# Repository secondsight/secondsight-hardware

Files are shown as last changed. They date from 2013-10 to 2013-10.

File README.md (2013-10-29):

secondsight
===========

3D Printable Head Mount Display for secondsight &amp; associated peripherals licensed under [Mozilla Public License, v. 2.0.](https://github.com/secondsight/secondsight-hardware/blob/master/LICENSE)

## Contents

- Example Assemblies
- Preparing to Build a Headset
- Building the Headset
- 3D Printing Plates & STL File Descriptions
- Source Files & Customisation
- Non-Source Files
- Logo

## Example Assemblies

Some of the STLs are not meant to be printed. They are just documentation to
show how that variant fits together. The names are the same as the variant file
with *-assembled* inserted before the extension - these are meant for assembly reference and 3D viewing.

You can view the final product here;

[Visor-C Assembled](https://github.com/secondsight/secondsight-hardware/blob/master/visor-C-assembled.stl) and [Visor-D Assembled](https://github.com/secondsight/secondsight-hardware/blob/master/visor-D-assembled.stl)

## Preparing to Build a Headset

There a few pre-requisites that you need to build the secondsight headset from
this project.

   1. Lenses
   2. Head strap
   3. 3D printer
   4. Android phone
   5. Open cell foam or neoprene

### Lenses

We have had reasonable luck with lenses in the 25mm to 37mm diameter range,
with a focal length of 50mm. The field of view is directly related to the
diameter of the lens. A 35-37mm diameter lens seems to give a view that covers
the whole phone at this focal length. A 25mm lens doesn't quite cover the whole
phone.

We have tried as high as 50mm diameter. That lens had a field of view larger
than the phone and required a larger visor design.

The current design is currently set for the 36mm Lens from [B&L 5X Aspheric Pocket Magnifier](http://www.amazon.com/Bausch-Lomb-Aspeheric-Packette-5x/dp/B000M755GK). We will be releasing our own pcx lens designs soon.

### Head strap

While you could use the headset by holding it to your face with your hands,
this would get old really quick. The headset is designed to use a 40mm wide
elastic strap to hold the headset. This gives good support without requiring an
extremely tight fit to avoid slipping.

### 3D Printer

You should be able to use any 3D printer with a large enough build volume. The
visor has been successfully printed in both ABS and PLA.

### Android Phone

The current visor design is optimized for the Galaxy S4 phone. The design does
not require exactly that phone, but it the front of the visor was designed around
the dimensions of the S4. It has been used with different phones that are close
to the same dimensions (e.g. Galaxy Nexus).

### Open Cell Foam or Neoprene

The hard plastic is mildly uncomfortable fitting directly against your face.
It's not painful, but it is hard plastic supporting a phone. A small amount of
foam applied to the back side of the visor makes the fit much more comfortable.

A cheap source of reasonable material is a cheap mousepad. You can easily cut
pieces to fit the visor.

## 3D Printing Plates & STL File Descriptions

To get a full visor, you will need to print one of the body variants
(*visor-C.stl* or *visor-D.stl*), the *lens_holders.stl* and the
*optics_support.stl*.

### visor-C.stl

In this variant, the body slopes smoothly from the face to the phone with no
flaring at all. The optics mounting hardware is printed inside the visor.

### visor-D.stl

In this variant, the body slopes smoothly from the face to the phone with no
flaring at all. The corners are slightly grooved to give less of a round feel.
The optics mounting hardware is printed inside the visor.

### lens\_holders.stl

This file contains the parts that support the lenses themeslves. The lens is
held between the longer barrel and the cap. This file contains parts for a pair
of lens holders.

### optics\_support.stl

This file contains the two support plates that connect the lens holders to the
visor body.

## Source Files & Customisation

Most of the source code for the hardware consists of OpenSCAD files.

### visor.scad

This is the main file that collects and assembles the parts the make up the
visor.  It has a number of parameters that control the final visor look.

#### Variants

Currently, we have two variants of the main structure of the visor: **C**
and **D**. Earlier prototypes were listed as variants A and B, but they are
no longer supported. In addition, you may want to print either the whole
visor or just parts of it. There are a pair of variables that allow you to
choose what variations you want to print.

   * variant - Choose the variant to print by setting this variable to the
     appropriate string
      - "C": See *visor-C.stl* above for a description. Used by the Makefile to
        generate *visor-C.stl*.
      - "D": See *visor-D.stl* above for a description. Used by the Makefile to
        generate *visor-D.stl*.
   * plate - Choose the subset of the visor to print.
      - "body": Print the main body of the visor.
      - "optics\_support": Print the lens support plates.
      - "lens\_holders": Print the lens holders.
      - "full\_optics": Print the lens holders and support plates all at once.
        Requires a fairly large build area. Not recommended.
      - "assembled": Show the assembled visor. Not printable!

You can either change these parameters in the *visor.scad* file or supply them
on the OpenSCAD command line if you want to automatically generate the STLs.
See the Makefile for examples of the use of these parameters.

#### Experimenting with Assembled View

There are a few parameters that you can change in the *assembled* view to get
an idea of how the visor will work in reality. Supplying a different value for
*lens* gives an idea of how the visor would look with that lens. Obviously,
this is easy for one of the defined lenses, and harder if you just want to try
out a lens. See the file *lenses.scad* to define a new lens to try.

Inside the optics\_assembled module, there are two potentially tweakable
parameters. The *xoff* value is half the IPD (Inter-Pupilary Distance). You can
either supply this directly or use one of the constants defined at the top of
*visor.scad*.

   * IPD\_min - minimum value for adults
   * IPD\_max - maximum value for adults
   * IPD\_avg - average value for adults
   * IPD\_avg\_male - average value for adult males
   * IPD\_avg\_female - average value for adult females

The other tweakable parameter is *lens_z*, which specifies the distance between
the phone and the lens. Normally, we use the defined value for the lens, but
you can change this value to see how the visor would look with the lens closer
to the phone or farther away.

#### User-Specific Parameters

The visor is currently configured to fit most adults relatively well. However,
there is a possibility that the visor could be more comfortable for a given
user by changing the fit slightly. The file *user_params.scad* contains a set
of user-specific changes for this purpose.

See the documentation below for a description of these parameters.

#### Phone-Specific Parameters

The visor is designed to work with the Galaxy S4. There should be little
difference from phone to phone. These parameters will only be changed to target
a different phone as the primary design.

These parameters should not be changed in most cases.

### visor\_body.scad

This file defines the main shape of the body of the visor. This is purely a
library file and generates no object if loaded directly. The *visor.scad* file
loads this *visor_body.scad* and calls the *main_body()* module to instantiate
the body.

### visor\_elastic\_mount.scad

This file defines the elastic band mounting system for the phone. Although not
the *coolest* design, this is functional and allows testing of the hardware.
It's main advantage is that it is simple and works with all phones.

### visor\_optics\_mount.scad

This file defines the hardware to support the lenses in the visor body. The
design has a few constraints that make the problem of mounting interesting.  We
want the lens to be held firmly, but weight is a consideration. Also not all
users are the same. Also, the *Interpupillary Distance* (IPD) is different from
person to person. We would like this to be easily adjustable for the user.

The optics mounting hardware takes these issues into account.

### optic\_plate\_support.scad

Defines the pieces of the model that supports the optics lens front plate in
the body of the visor. Defines the ledges, the tabs and the slots.

### lenses.scad

This file contains functions to define and use descriptions of particular
lenses. We want designs to be able to depend on both the physical and optical
characteristics of a lens, without having a bunch of random constants to deal
with (and pass around). This file defines a vector structure and accessors to
keep those parameters in check.

#### lens\_descriptor(name)

This function returns the vector that describes a lens we already know. You
can think of it as a factory object for known lenses. It currently has values
for the lenses we used in prototyping.

#### Accessor methods

Each accessor takes the lens description as a parameter and returns the
requested data from the vector. This is a lot more readable than just dealing
with random vector indices. All lengths are in mm.

   * lens\_diam(lens) - lens diameter
   * lens\_focal\_length(lens) - focal length
   * lens\_phone\_offset(lens) - measured nominal distance from lens to phone
   * lens\_fov(lens) - measured minimum field of view at the phone\_offset
   * lens\_rim\_thickness(lens) - thickness of the rim of the lens
   * lens\_front\_height(lens) - distance from rim to the front of the lens
   * lens\_thickness(lens) - overall thickness of the lens
   * lens\_back\_height(lens) - distance from the rim to the back of the lens

### polybody.scad

The visor body is designed around a ten-sided polyhedron. Some of the
parameters and code for this polyhedron are needed in multiple files.
Separating the code into this file makes it easier to reuse.

### user\_params.scad

This file contains only constants that describe some user-specific sizes.

Although we don't expect these to change, a particular user might be able to
get a better fit by changing the user-specific parameters.

   * *user_temple_distance* - distance from temple to temple in mm.
   * *forehead_depth* - distance from temple to front of forehead in mm.
   * *eye_forehead_offset* - inset distance of eyes from forehead

We will try to get these parameters reasonable for most adults, but tweaking
them may generate a more comfortable fit.

The only one that is likely to change much would be *user_temple_distance*.
People with wider or narrower faces may want to change this parameter.

## Non-Source Files

### Makefile

To simplify the creation of STL files from the OpenSCAD source, the project
also includes a *Makefile*. You can use most variants of the *make* development
tool to generate the STLs from the command line. The Makefile contains two
variables that probably require changing to use in your environment.

   * *OPENSCAD* - full path to the OpenSCAD program on your system
   * *SLIC3R* - (optional) full path to the slic3r program on your system

You do not need to use slic3r to generate your gcode files. If you do, the
Makefile contains targets to help.

### config.ini

This is a *slic3r* configuration that has been used to create gcode files for
the visor STLs.

## Logo

The font used in the logo uses the OpenSans Regular font, which has been ported
for use with OpenSCAD by the Brad Pitcher. His implementation is available at
http://www.thingiverse.com/thing:13677 and is released under a CC by-sa
license.

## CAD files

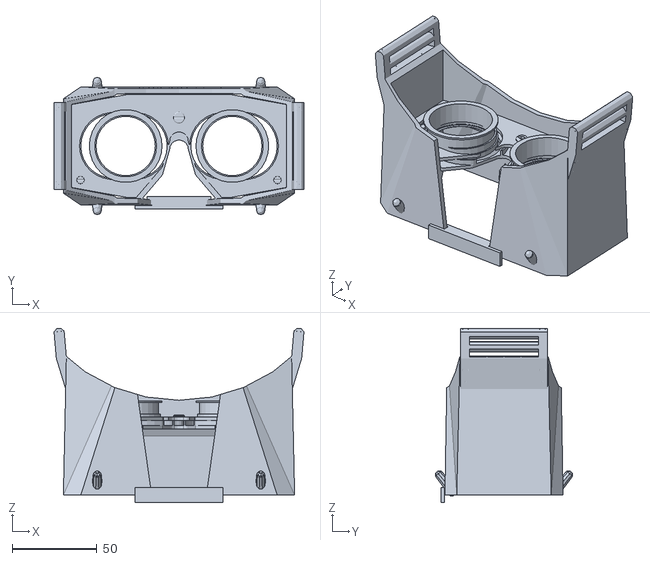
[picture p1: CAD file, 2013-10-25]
visor-D-assembled.stl
147.7 x 81.1 x 103.0

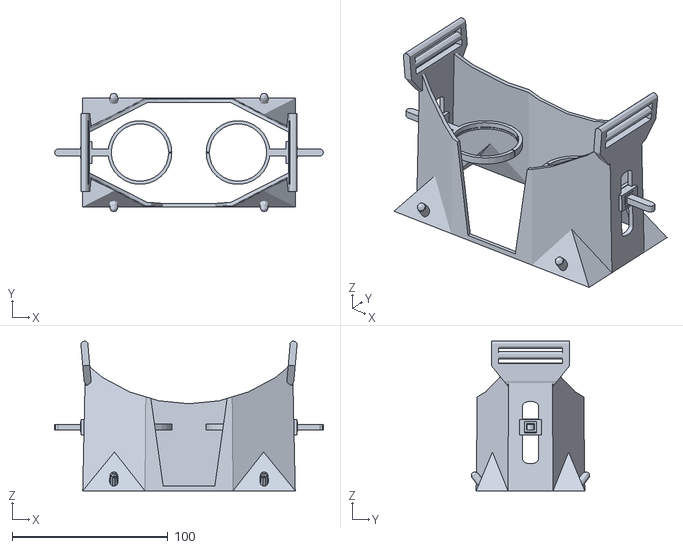
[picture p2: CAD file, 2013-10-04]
visor-assembled.stl
172.8 x 76.1 x 96.3

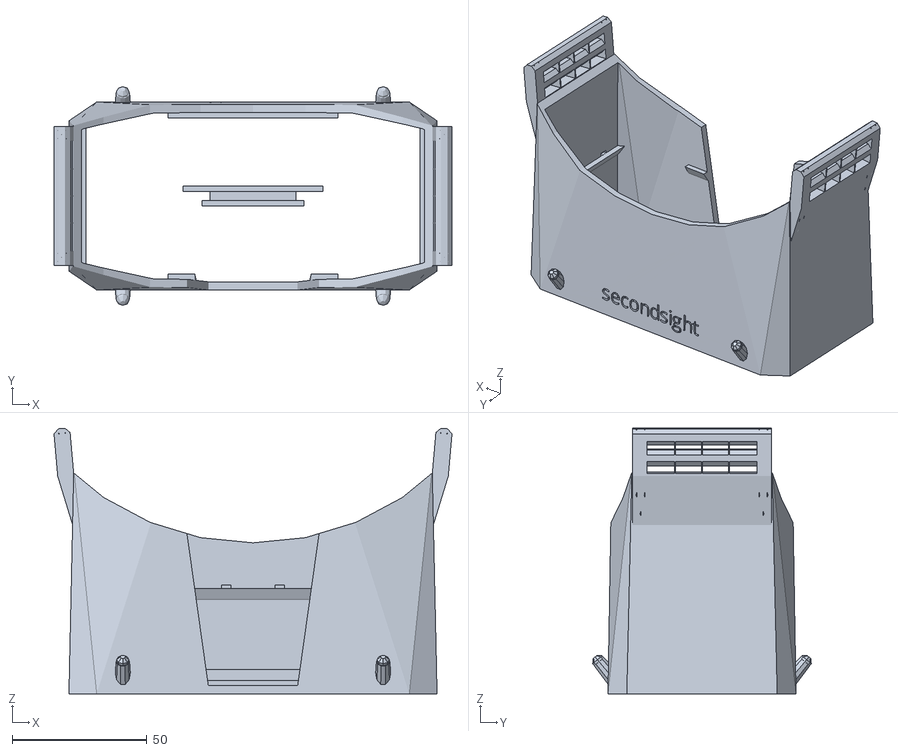
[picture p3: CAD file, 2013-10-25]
visor-C.stl
147.7 x 81.1 x 98.5

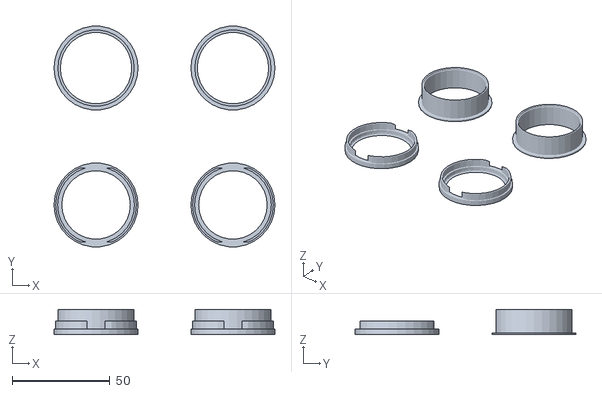
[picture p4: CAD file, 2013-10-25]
lens_holders.stl
113.0 x 112.8 x 13.0

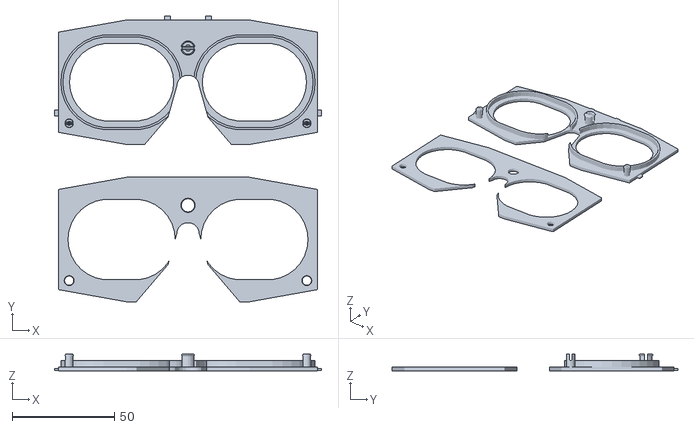
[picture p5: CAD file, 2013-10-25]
optics_support.stl
130.7 x 139.8 x 8.25

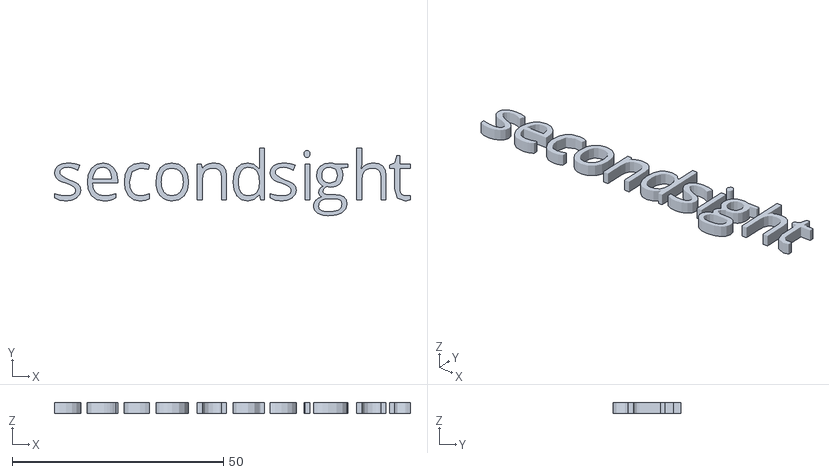
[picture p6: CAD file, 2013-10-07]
secondsight_logo.stl
84.2 x 16.0 x 2.50

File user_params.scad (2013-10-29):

/* This Source Code Form is subject to the terms of the Mozilla Public
 * License, v. 2.0. If a copy of the MPL was not distributed with this
 * file, You can obtain one at http://mozilla.org/MPL/2.0/. */

// secondsight Visor project
// Copyright 2013 by secondsight.io, Some Rights Reserved.
//
// Definition of user-specific parameters for the secondsight hardware

user_temple_distance=116; // temple-to-temple distance
forehead_depth=27.5;      // temple to front of forehead distance
eye_forehead_offset=5;    // distance from forehead to eye

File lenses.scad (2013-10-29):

/* This Source Code Form is subject to the terms of the Mozilla Public
 * License, v. 2.0. If a copy of the MPL was not distributed with this
 * file, You can obtain one at http://mozilla.org/MPL/2.0/. */

// secondsight Visor project
// Copyright 2013 by secondsight.io, Some Rights Reserved.
//
// Standardize a lens description for the secondsight headset.

//  Creating a pseudo-object using a vector and a set of functions to access
//  the defined attributes.

function lens_descriptor(name) = (name == "ebay 50x50") ? [ 50, 50, 42, 75, 2, 7.35, 12.45 ]
    : name == "edmund 25x50" ? [ 25, 50, 44, 50, 1.25, 3, 4.25 ]
    : name == "edmund 25x25" ? [ 25, 25, 23, 30, 1.25, 6.15, 7.4 ]
    : name == "b&l 35 5x"    ? [ 37, 50, 41, 60, 1.9, 3, 8 ]
    : [];

function lens_diam( lens ) = lens[0];
function lens_rad( lens ) = lens[0]/2;
function lens_focal_length( lens ) = lens[1];
function lens_phone_offset( lens ) = lens[2];
function lens_fov( lens ) = lens[3];
function lens_rim_thickness( lens ) = lens[4];
function lens_front_height( lens ) = lens[5];
function lens_thickness( lens ) = lens[6];
function lens_back_height( lens ) = lens[6]-lens[5]-lens[4];

// Define a model of the lens described by 'lens'
//
// lens - descriptor for the lens to model
module lens_model( lens )
{
    union()
    {
        //front
        if( lens_front_height(lens) > 0 )
        {
            assign( rad_up=(lens_rad(lens)*lens_rad(lens)+lens_front_height(lens)*lens_front_height(lens))/(2*lens_front_height(lens)) )
            {
                translate( [0,0,lens_rim_thickness(lens)/2] )
                intersection()
                {
                    translate( [0,0,lens_front_height(lens)-rad_up] )
                        sphere( r=rad_up, center=true, $fn=50 );
                    cylinder( r=lens_rad(lens), h=lens_front_height(lens) );
                }
            }
        }
        //rim
        cylinder( h=lens_rim_thickness(lens), r=lens_rad(lens), center=true );
        //back
        if( lens_back_height(lens) > 0 )
        {
            assign( rad_up=(lens_rad(lens)*lens_rad(lens)+lens_back_height(lens)*lens_back_height(lens))/(2*lens_back_height(lens)) )
            {
                translate( [0,0,-lens_rim_thickness(lens)/2] )
                intersection()
                {
                    translate( [0,0,-lens_back_height(lens)+rad_up] )
                        sphere( r=rad_up, center=true, $fn=50 );
                    translate( [ 0,0, -lens_back_height(lens) ] ) cylinder( r=lens_rad(lens), h=lens_back_height(lens) );
                }
            }
        }
    }
}

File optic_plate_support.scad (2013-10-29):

/* This Source Code Form is subject to the terms of the Mozilla Public
 * License, v. 2.0. If a copy of the MPL was not distributed with this
 * file, You can obtain one at http://mozilla.org/MPL/2.0/. */

// secondsight Visor project
// Copyright 2013 by secondsight.io, Some Rights Reserved.
//
//  Define the tab/slot system for attaching the optics plate to the body.

// Fit factors
slide_gap=0.25;
fit_gap=0.15;

// Tab sizing
tab_length=3;
tab_height=1;

module support_slot( depth )
{
    long=tab_length+2*slide_gap;
    height=tab_height+2*fit_gap;
    translate( [ 0, 0, height/2 ] ) cube( [ long, depth, height ], center=true );
}


module support_tab( depth )
{
    long=tab_length;
    height=tab_height;
    translate( [ 0, 0, height/2 ] ) cube( [ long, depth, height ], center=true );
}

module support_ledge_slots( x_off, y_off, z_off )
{
    gap=1.1;
    depth=2;
    spread=10;
    drop=15+gap;
    translate( [-spread, y_off+gap, z_off+0.1] ) support_slot( depth );
    translate( [ spread, y_off+gap, z_off+0.1] ) support_slot( depth );
    translate( [ x_off+gap, -drop, z_off+0.1] ) rotate( [ 0, 0, 90 ] ) support_slot( depth );
    translate( [-(x_off+gap), -drop, z_off+0.1] ) rotate( [ 0, 0, 90 ] ) support_slot( depth );
}

module support_ledge_tabs( x_off, y_off, z_off )
{
    gap=1.1;
    fudge=0.1;
    depth=gap+1-fit_gap;
    spread=10;
    drop=15;
    gap_off=depth/2-fudge;
    translate( [-spread, y_off+gap_off, z_off+fudge] ) support_tab( depth );
    translate( [ spread, y_off+gap_off, z_off+fudge] ) support_tab( depth );
    translate( [ x_off+gap_off, -drop, z_off+fudge] )  rotate( [ 0, 0, 90 ] ) support_tab( depth );
    translate( [-(x_off+gap_off), -drop, z_off+fudge] ) rotate( [ 0, 0, 90 ] ) support_tab( depth );
}

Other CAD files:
visor-C-assembled.stl
visor-D.stl
hmd.scad
polybody.scad
viewer_body.scad
visor.scad
visor_body.scad
visor_elastic_mount.scad
visor_optics_mount.scad

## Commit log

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2013-09-12 First attempt at front mount.
    Still pretty blocky and I need to check the angle for printing.
    [viewer_body.scad]
2013-09-13 Corrected widths error.
    I had forgotten about converting the 'face-to-face' width to a radius
    before generating the cylinders. This change the code to take that into
    account.
    I also sloped the main body. Despite the mistake, the side of the viewer
    that fit against the face was almost perfect, even if it wasn't what I
    planned. Now, the front is better suited to match the phone and the back
    should still fit against the face.
    [viewer_body.scad]
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2013-09-13 Final cleanup of this pass.
    Push unimportant details down as far as possible. The two polyprism
    modules now deal with all of the fiddly bits instead of spreading the
    details over multiple modules.
    Remove some unnecessary variables.
    Add some comments for later readability.
    [viewer_body.scad]
2013-09-13 Adjust angle to reduce chance of overhang failure.
    [viewer_body.scad]
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2013-09-13 Close bottom front for stability.
    [viewer_body.scad]
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2013-09-13 Modify the strap holders for comfort.
    The straight up version of the strap holder fit a little tight against
    the temples. This version has them lean outward about 5 degrees on each
    side. Hopefully this is more comfortable.
    [viewer_body.scad]
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2013-09-16 Restructure the scad files.
    Separating major components of the code into separate scad files to
    simplify making different variants without a whole lot of conditionals.
    The main body deserves it's own component.
    The phone mount will change, so it has it's own component.
    Added a main file that brings together components.
    Also renamed "viewer" to "visor". Better term.
    [visor.scad, visor_body.scad, visor_elastic_mount.scad]
2013-09-16 Modify test variant for mount test.
    Modified the "test" variant so that I'm only printing the front part
    of the visor. This exposes the elastic mount points for testing without
    requiring the whole visor.
    [visor.scad]
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2013-09-16 Improve elastic mount printability.
    The mount points failed in terms of the look of the print. Structurally,
    they did pretty well.
    Hopefully these changes and the cooling changes in config.ini will
    result in a better print.
    [visor_body.scad, visor_elastic_mount.scad]
2013-09-16 Reduce dependence on globals.
    Modified several modules to take parameters instead of depending on the
    global values. Added more documentation for the new parameters.
    [visor.scad, visor_body.scad]
2013-09-16 Make the wall thickness consistent in x and y.
    The code I was using to "squash" the rectangle and octagon had a flaw
    that reduced the size of the walls at the top and bottom of the visor.
    Once I realized what it was, the fix was pretty obvious.
    [visor_body.scad]
2013-09-17 New design for strap mount.
    Make the strap mount a little thinner.
    Make two slots to lock the strap in place
    Lengthen the mount slightly.
    [visor.scad, visor_body.scad]
2013-09-17 Replace the square center rod with an octagon.
    This looks like a much nicer fit. I need to print to see if it is strong
    enough.
    [visor_body.scad]
2013-09-18 First attempt failed because top wasn't strong enough.
    [visor_body.scad]
2013-09-18 Make slots for optics mounts.
    Also corrected the forehead_depth parameter, which I had mis-labeled.
    Extended depth to match optics information from Dmitry.
    [visor.scad, visor_body.scad, visor_optics_mount.scad]
2013-09-18 Fix strap mount height.
    [visor_body.scad]
2013-09-18 Add STLs to git.
    Jarrad pointed out that github has an STL diff viewer now.
    Add the main STLs to version control.
    Fix .gitignore to not ignore STLs.
    Modify the Makefile to make generating main STLs easier.
    [visor-A.stl, visor-B.stl]
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2013-09-18 Correct merging error.
    [visor.scad, visor_body.scad]
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2013-09-18 First try at a lens holder.
    Based on the dive design. Not any clips, yet. It will be hard to design
    that part until I get the lenses in the mail.
    [visor_optics_mount.scad]
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2013-09-19 Attempt a better fit for slider.
    Tighten the inside/outside fit, so that gluing is not required.
    Tighten the slot fit so that it doesn't wiggle as much.
    Add slope to the hole for the lens holder to make it parallel to the
    phone.
    [visor.scad, visor_optics_mount.scad]
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2013-09-19 Prepare main file to print whole visor.
    Set up both A and B variants to print with the optics mounting hardware
    on the same plate as the visor body.
    [visor.scad]
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2013-09-19 Make it possible to print in parts.
    Added a part parameter that allows for printing the body, the optics
    support, or both.
    [visor.scad]
2013-09-19 Adjust the slider a little more.
    Spacing between inside and outside corrected.
    Add a little spacing to allow lens holder to move.
    [visor_optics_mount.scad]
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2013-09-20 Better fit for slider outside.
    Modified the slider so that the core should go all of the way through.
    Marked the top of the piece slightly to make assembly easier.
    [visor_optics_mount.scad]
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2013-09-20 Correct outside slider through-hole.
    The new version resulted in an outside slider with a solid piece through
    the hole. Extend the cut to make certain it stays.
    [visor_optics_mount.scad]
2013-09-20 Add support for generating an "assembled" STL.
    This STL serves as documentation for how the parts should fit together.
    [visor-assembled.stl, visor.scad]
2013-09-20 Move the 'top of slider' marks.
    For some reason, the little cylinder on the outside slider caused a
    glitch in slic3r that created a filled layer all the way across when
    the little cylinder marker was on the lip. Moved to top without
    side-effects. Made the same change to the inside slider, because it was
    invisible on the original.
    [visor_optics_mount.scad]
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2013-09-23 Refactor to make changing lens parameters easier.
    Factored out the lens diameter.
    Calculate some values relative to the lens parameters.
    Added transparent lenses to the assembled view to help visualize
    the offsets better.
    [visor.scad, visor_optics_mount.scad]
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2013-09-26 Add support for a lens description.
    Lenses are a little too complicated to be described with a couple of
    numbers to pass around. The file lenses.scad defines support functions
    that allow us to treat a vector of numbers as if it we are descriptive
    structure.
    Define the three lenses we are currently working with.
    Modify the code to use the new lens descriptor rather than just a lens
    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
    [lenses.scad, visor.scad, visor_optics_mount.scad]
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2013-09-27 Improved assembly STL.
    Replaced ad-hoc-ery with parameters based on the actual visor/user/lens
    combination in use.
    The result now works for any variant or lens size.
    [visor.scad]
2013-09-27 Fix the little angles on the nose slice.
    [visor_body.scad]
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2013-10-01 Add parameters for the new B&L lens.
    It's a little bigger than the 35mm we were hoping for, but the FOV
    is perfect.
    [lenses.scad, visor.scad]
2013-10-01 Finish cleanup with new lens.
    A little cleanup of visor.scad. Add documentation of changes to the
    "assembled" plate. Generate new STLs.
    [visor-A.stl, visor-B.stl, visor-assembled.stl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]
2013-10-01 Fix "assembled" model.
    When rearranging the model to make tweaking it easier, I reverse the
    order of two variables that were dependent on each other.
    Fixed that.
    [visor-A.stl, visor-B.stl, visor-assembled.stl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]
2013-10-02 Support making visor variant C.
    Update Makefile to build visor-C.stl.
    Add lenses.scad to dependencies for everyone.
    The current code to enable variant C is nasty. Need to refactor.
    [visor-A.stl, visor-B.stl, visor-assembled.stl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]
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2013-10-02 Clean up elastic mount logic.
    Remove the need to pass the variant down this far.
    Still not perfect, but it's cleaner than the first pass.
    [visor_body.scad, visor_elastic_mount.scad]
2013-10-02 Clean up visor body description.
    File no longer depends directly on variant.
    Factor out parameters that may need to be calculated later.
    Add documentation to new modules as needed.
    [visor.scad, visor_body.scad]
2013-10-02 Correct height of straps on new body.
    [visor-A.stl, visor-B.stl, visor-C.stl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]
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2013-10-02 Fix Makefile error that could generate wrong STLs
    [visor-A.stl, visor-B.stl, visor-C.stl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]
2013-10-03 Incorporate strap mount into walls.
    Also required widening the sides to allow the straps to be in-line.
    [visor_body.scad]
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2013-10-03 Third try for full ring.
    On the top, thinner ridge in 4 pieces, instead of thick ridge most of
    the way around.
    [visor_optics_mount.scad]
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2013-10-04 Back to two supports.
    Two worked slightly better than three and requires less post-processing.
    [visor_body.scad]
2013-10-04 Restore sloped version of strap mount for variants
    The A and B variants can only be made to work with the slope-sided
    version of the strap mount. The sides are too narrow otherwise.
    [visor.scad, visor_body.scad]
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2013-10-04 Cleanup internal docs and generate STLs.
    Documented the new modules in visor_body.
    Generate STLs.
    [visor-A.stl, visor-B.stl, visor-C.stl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]
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2013-10-08 Add internal strengthening in both directions.
    [visor_body.scad]
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2013-10-08 Attempt to remove attempts to merge STLs.
    The .gitattributes file tells git to keep our version of all STL files
    rather than try to merge them. This should reduce spurious conflicts
    during merges. There's really no reasonable way to correct the
    conflicts.
    We are keeping the STLs in version control despite being generated files
    because it saves people from needing to use OpenSCAD to generate them
    and they are viewable on github.
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2013-10-08 Cleanup strap mount code.
    Fix the support-removal code to match the new parameters.
    Factor out some calculations and constants so they are not repeated.
    [visor_body.scad]
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2013-10-16 Make the holder cap fit tighter and higher.
    The previous design fit a little loose.
    The new design should be a little tighter and has more area for the
    friction fit. I've gut two holes in the side of the top to help it fit
    the gaps better and to give a little flex in the fit.
    [visor_optics_mount.scad]
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2013-10-16 Correct call to template distance calc.
    [visor.scad]
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2013-10-16 Add gap to avoid nose with the lens plate.
    Add a little cleanup of constants and minor code cleanup, in addition to
    the nose gap.
    [visor_optics_mount.scad]
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2013-10-18 Correct printability of plate.
    [visor.scad, visor_optics_mount.scad]
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2013-10-22 Next test of support pins.
    Widened gap for small pins.
    Made pins rounder.
    Corrected positioning and height of pins on test bed.
    Minor cleanups for readability.
    [visor.scad, visor_optics_mount.scad]
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2013-10-22 Optimize build plates.
    I'm trying to get as much as possible on a single build plate. It's not
    working particularly well. The new lens holders won't print inside the
    visor and the lens plates pretty much triple the area needed for the
    print.
    Even printing all of the optics on a single plate doesn't work well. I
    may need to replace the single plate with 3 separate plates.
    [visor.scad]
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2013-10-22 Fix assembled view.
    [lens_holders.stl, optics_support.stl, visor-C-assembled.stl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]
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2013-10-23 Corrected renderings for new optic support.
    [lens_holders.stl, optics_support.stl, visor-C-assembled.stl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]
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2013-10-24 Correct accidental change to lens containment rims.
    [visor_optics_mount.scad]
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
